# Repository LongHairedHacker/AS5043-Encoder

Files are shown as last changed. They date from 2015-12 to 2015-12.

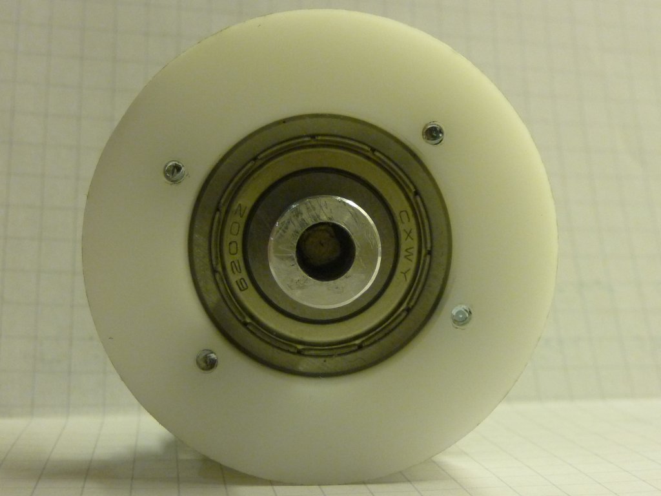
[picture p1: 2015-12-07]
photos/assembled2.jpg

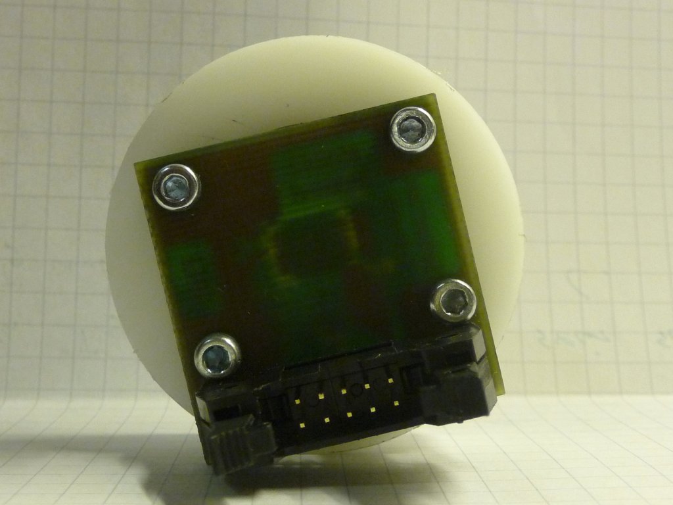
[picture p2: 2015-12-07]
photos/assembled4.jpg

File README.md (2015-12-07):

AS5043-Encoder
==============

This repos contains all the plans and software necessary to build a magnetic rotary encoder using the AS4053.

The setup for this chip is rather simple,
you need a few external components and a neodymium magnet that is attached to your rotating axis.
Then the sensor is placed below the magnet.
Since it uses the magnetic field neither dirt nor light will be a problem.
The sensor will output the angle of the magnet relative to a programmable starting position via analogue output
or via a [SSI](https://en.wikipedia.org/wiki/Synchronous_Serial_Interface)-Style interface.
(See the datasheet for details.)
With 10bit resolution it should be theoretically possible to measure the current angle in 0.35° steps.

The guys at austria microsystems were kind enough to send me 3 AS5043 and 3 AS5030 (similar part 8bit resolution).
*Big thanks to them.*

Mechanical Parts
----------------
There are 2 plans available :

* A version that can be build using a lathe
* A 3D printable version created with open scad
* A 3D printable version created with freecad

The plans for the first version can be found in the repo directory [chasis/lathe](chasis/lathe).
You can simply print out the pdfs and hand them over to someone who has access to a lathe.
He or she should know what to do with them.

For the 3D printable versions simply run the stl files through your 3D printing toolchain.
The 3D printable versions can be found in [chasis/3d_printable_scad](chasis/3d_printable_scad)
and [chasis/3d_printable_freecad](chasis/3d_printable_freecad).

You will also need some M3 screws and nuts which you should find in your favorite hardware store.
For the magnets I'd recommend browsing ebay for 5mmx5mmx5mm neodym magnet cubes.
The ball bearing you'll need is a common 6200Z bearing.
Again try your hardware store or ebay.
There you'll possible also find some M3 5mm long distance bolts, that are used in the lathe version of the chassis.

Software
--------
The software part required some tricks to get it working.
Comparing the signal diagrams for SPI in Atmels datasheet and for *SSI* in the AS5043 a small problem becomes obvious.
The AS5043 needs a clock signal that is high in idle stage and the bits will be shifted out on the positive clock edge.
That sounds very much like the SPI mode 3 in Atmel-speech: Clock high on idle and data will be read on every rising edge.
Leaving us with one problem: The Atmel hardware SPI can read the miso pin only at a clock edge.
As mentioned before data is sampled at the rising edge for mode 3.
So shifting out and reading would be done almost synchronous and due to signal rise and fall times this will probably fail 90% of the time.

The solution is to use mode 2: Clock high on idle and bits are read at the falling edge.
Now we have a different problem.
The first bit will be read before it was shifted out by the AS5043.
Using AVR SPI it is possible to read one byte at time, so two read cycles are required to read the full 16bit encoder output.

The first byte read in mode 2 will look like this:

| Bit 7 | Bit 6 | Bit 5 | Bit 4  | Bit 3 | Bit 2 | Bit 1 | Bit 0 |
|---|---|---|---|---|---|---|---|
| **garbage** | D9 | D8 | D7 | D6 | D5 | D4 | D3 |

Reading the next 8bit will work fine since the 8th bit was shifted out on the last rising edge after reading the first 7 bit.
It will be read as the bit in on the falling edge for the next byte,
which looks like this:

| Bit 7 | Bit 6 | Bit 5 | Bit 4  | Bit 3 | Bit 2 | Bit 1 | Bit 0 |
|---|---|---|---|---|---|---|---|
| D2 | D1 | D0 | OCF | COF | LIN | MAG INC | MAG DEC |

Everything after the *D0*-bit is status information needed in order to decide whether the measurement was valid.
Unfortunately important status bit is still missing.
The 16th bit contains the parity information required to check against transmission errors.
It is shifted out on the last rising edge when reading the second byte. Since the clock line is high afterwards,
the data line will stay on the 16th bits level until the next read is performed.
It can read by manually checking the *MISO* pins state.
The rest is just nifty bit shifting.

It is also important not to use the SS of the AVR mcu for chip select,
since this pin will change to high after reading the first byte, which causes the AS5043 to reset its *SSI* interface.

The code for this can be found in [AS5043.c](firmware/lib/AS5043.c) and in [AS5043.h](firmware/lib/include/AS5043.h).

A simple code for testing can be found in the directory [firmware/demo](firmware/demo).
main.c contains code for an Atmega8 or Atmega328 that reads the encoder, calculates the rotation in degrees and sends out using the uart.
cube.py is a simple receiving is the receiving part running on your computer.
It uses PyOpenGL to display a wireframe cube and rotate it according to the encoders rotation value.

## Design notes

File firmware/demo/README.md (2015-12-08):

Running the Demo
================

Compiling
---------
To compile this example you will need make, avrgcc avr-binutils and the avrlibc.
If you are reading this I assume you already have an avr toolchain in place.
Also you'll need avrdude to flash your avr.

The makefile takes 3 optional parameters:
 * **F_CPU** Clock speed of your controller in Hertz (default: 16000000)
 * **AVRMCU** The name of your microcontroller, currently only atmega8 and atmega32p are supported (default: atemga8)
 * **ISPPORT** The serial interface for `make flash` (default: /dev/ttyACM0)

 To compile and flash the code run (assuming there is a serial bootloader like optiboot present on your controller):
 ```
 make
 make flash
 ```

 If you want to run the code on your Arduino try:
 ```
 make AVRMCU=atmega328p ISPPORT=/dev/ttyACM0
 make AVRMCU=atmega328p ISPPORT=/dev/ttyACM0 flash
 ```

Afterwards connect the encoder and start a terminal emulator of your choice on your serial interface.
Configure it for **38400** Baud, **8** Bit, **N**o Parity and **1** stop bit.
If you start sending newlines to the microcontroller, you should see it respond with measurements in plain ASCII.
If your are seeing binary garbage, you either have the wrong baudrate or degree_mode not set to 1.

You can also run cube_demo.py on this interface if you have PyOpengl and PySerial installed.
It might be necessary to change the SERIAL constant on line 16 to the correct interface.

Connecting the encoder
----------------------

Simply connect the encoder according to the following table:

| AS5043 | Breakout Pin | AVR | Arduino |
|---|---|---|---|
| PROG | 1 | GND | GND |
| DO | 3 | PB4 (MISO) | digital pin 12 |
| CLK | 5 | PB5 (SCK)  | digital pin 13 |
| CS | 7 | PB2 (SS) | digital pin 10 |
| MODE | 9 | GND | GND |
| VDD5V  | 2 | +5v | +5v |
| VSS | 4 | GND | GND |

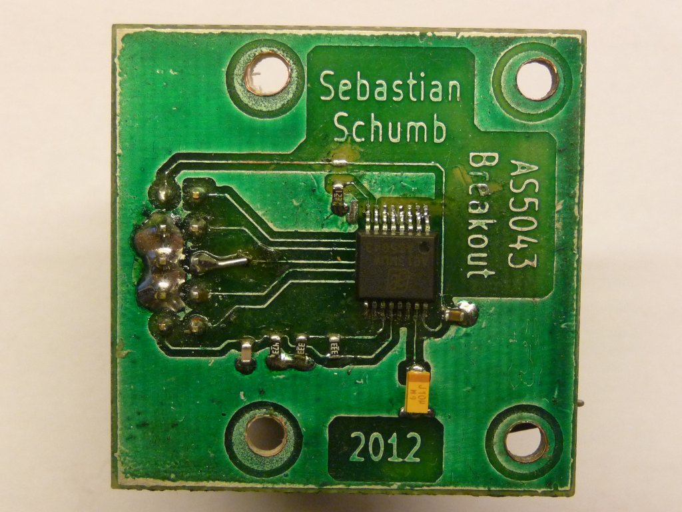
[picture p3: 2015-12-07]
photos/sensorboard_final1.jpg

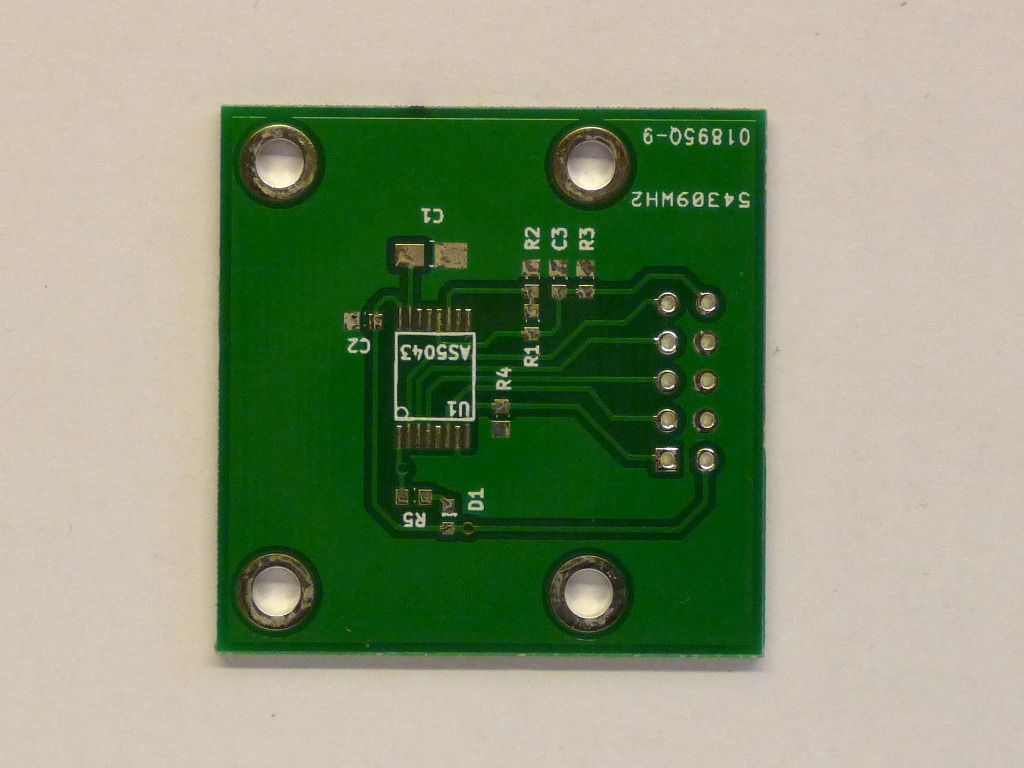
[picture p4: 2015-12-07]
photos/boardv12_bottom.jpg

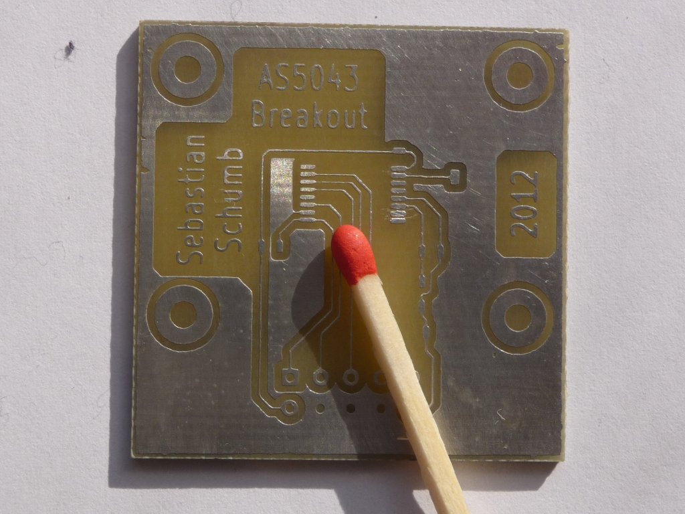
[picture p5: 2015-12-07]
photos/sensorboard_tin2.jpg

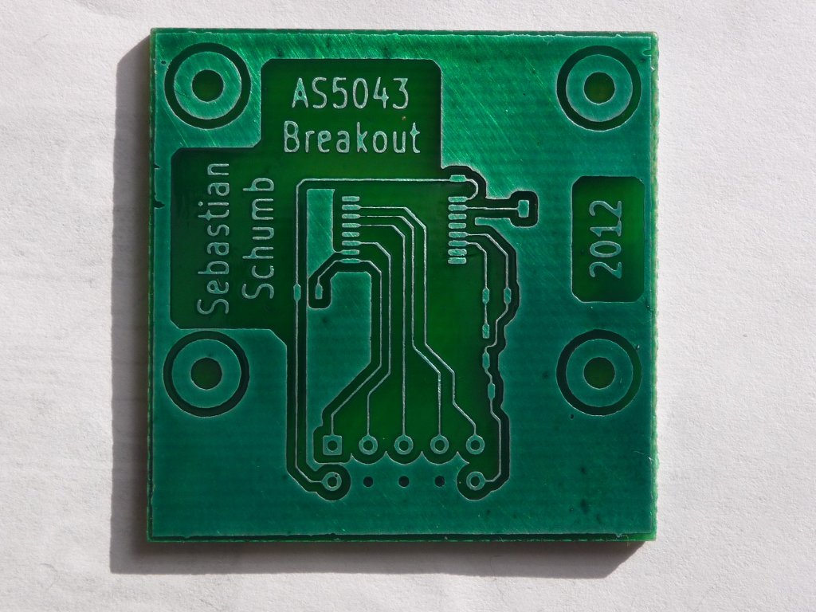
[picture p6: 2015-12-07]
photos/sensorboard_greencoat1.jpg

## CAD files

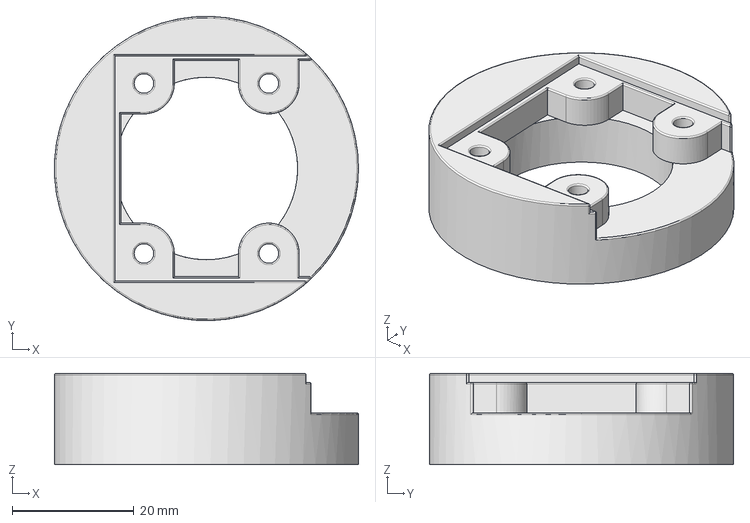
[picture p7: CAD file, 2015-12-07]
chasis/3d_printable_freecad/chasis.fcstd
50.0 x 50.0 x 15.0 mm

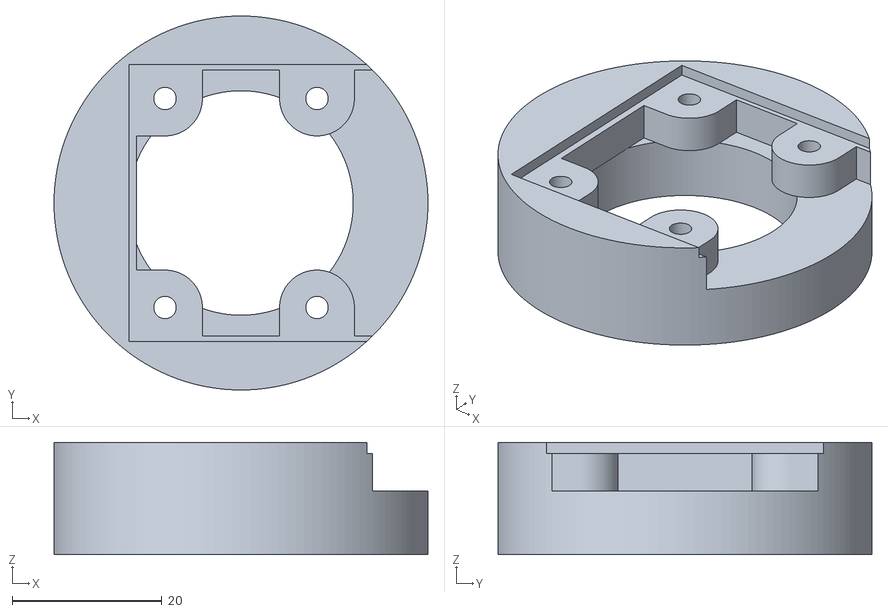
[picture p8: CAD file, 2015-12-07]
chasis/3d_printable_scad/sensor_chasis1.stl
50.0 x 50.0 x 15.0

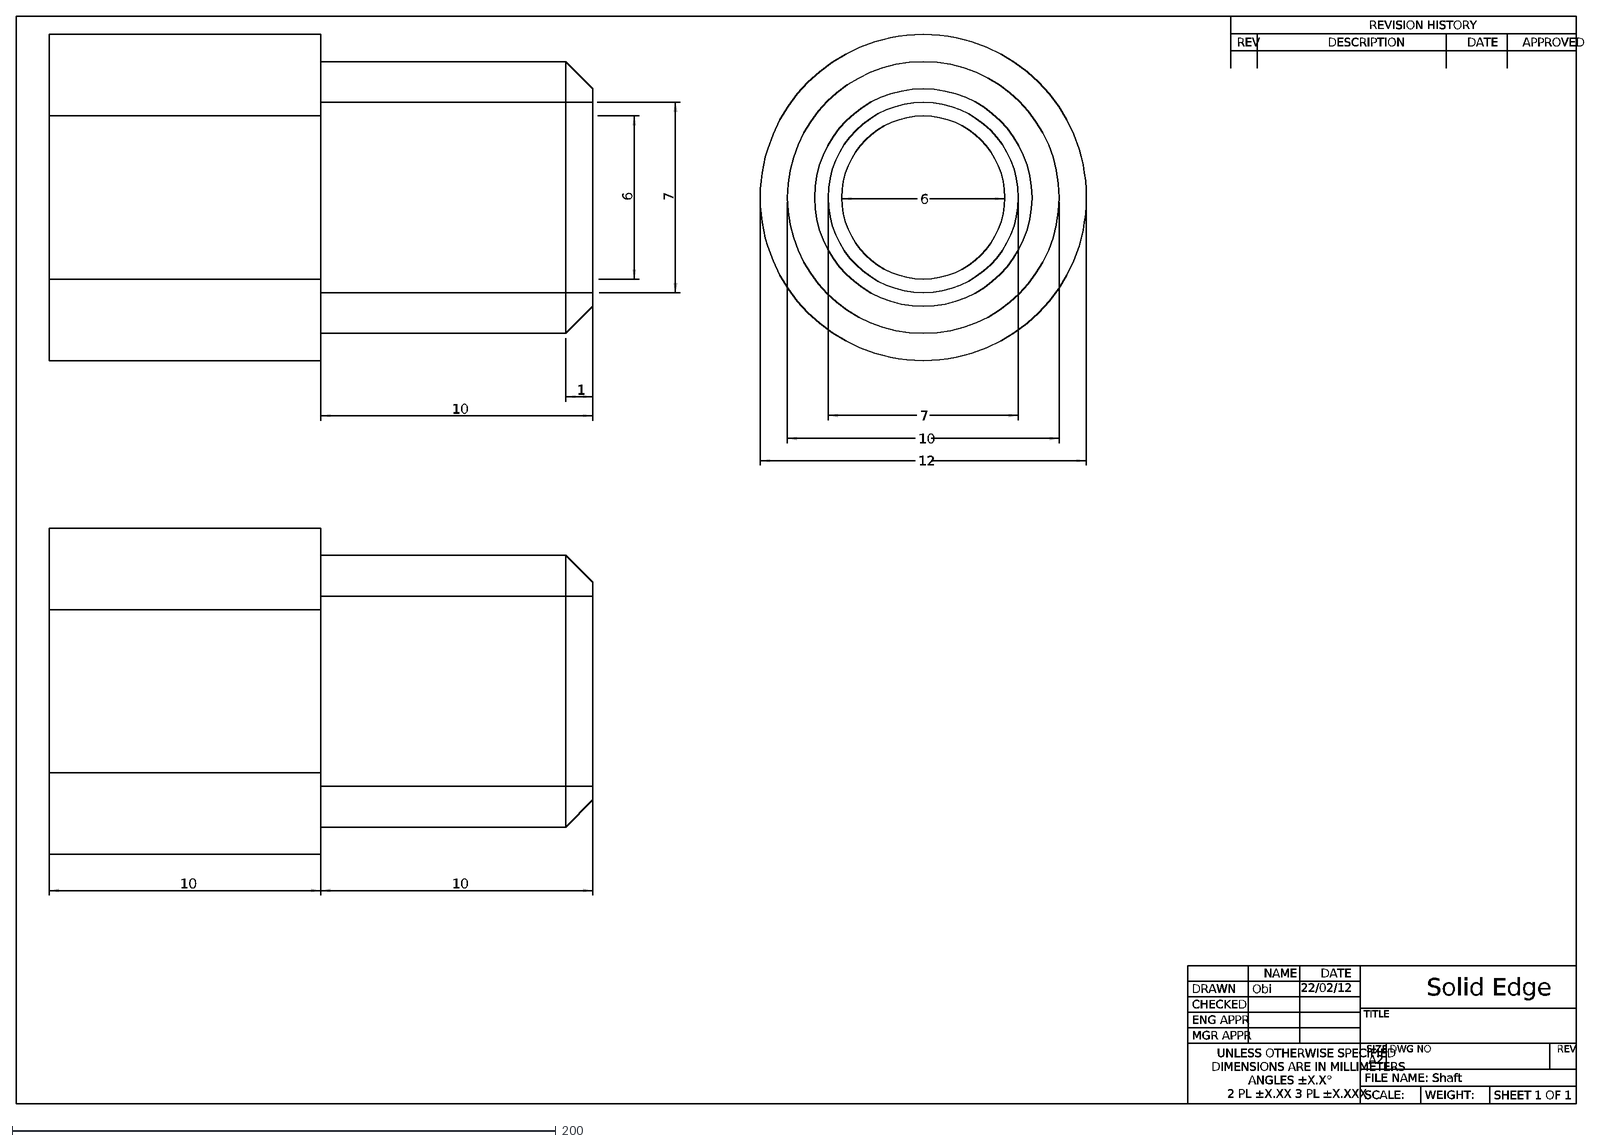
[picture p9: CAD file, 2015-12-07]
chasis/lathe/shaft.dxf
DRAWN
CHECKED
ENG APPR
MGR APPR
UNLESS OTHERWISE SPECIFIED
DIMENSIONS ARE IN MILLIMETERS
ANGLES ±X.X°
2 PL ±X.XX 3 PL ±X.XXX
NAME
DATE
Solid Edge
TITLE
SIZE
A2
DWG NO
REV
SCALE:
WEIGHT:
REVISION HISTORY
DESCRIPTION
APPROVED
1
10
6
7
12
Obi
22/02/12
FILE NAME: Shaft
SHEET 1 OF 1

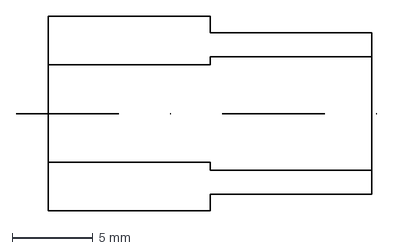
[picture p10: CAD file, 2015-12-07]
chasis/prototype/shaft.dxf
22.3 x 12.0 mm

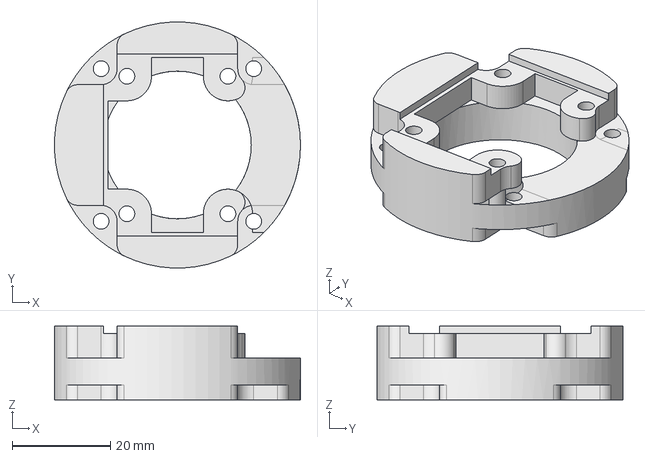
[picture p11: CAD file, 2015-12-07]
chasis/testrig_freecad/testrig.fcstd
50.0 x 49.9 x 15.0 mm

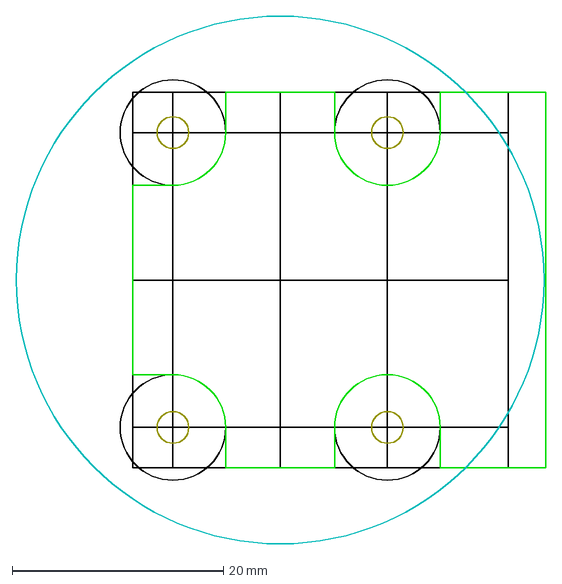
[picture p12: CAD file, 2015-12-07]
chasis/3d_printable_scad/cut-out.dxf
50.2 x 50.0 mm

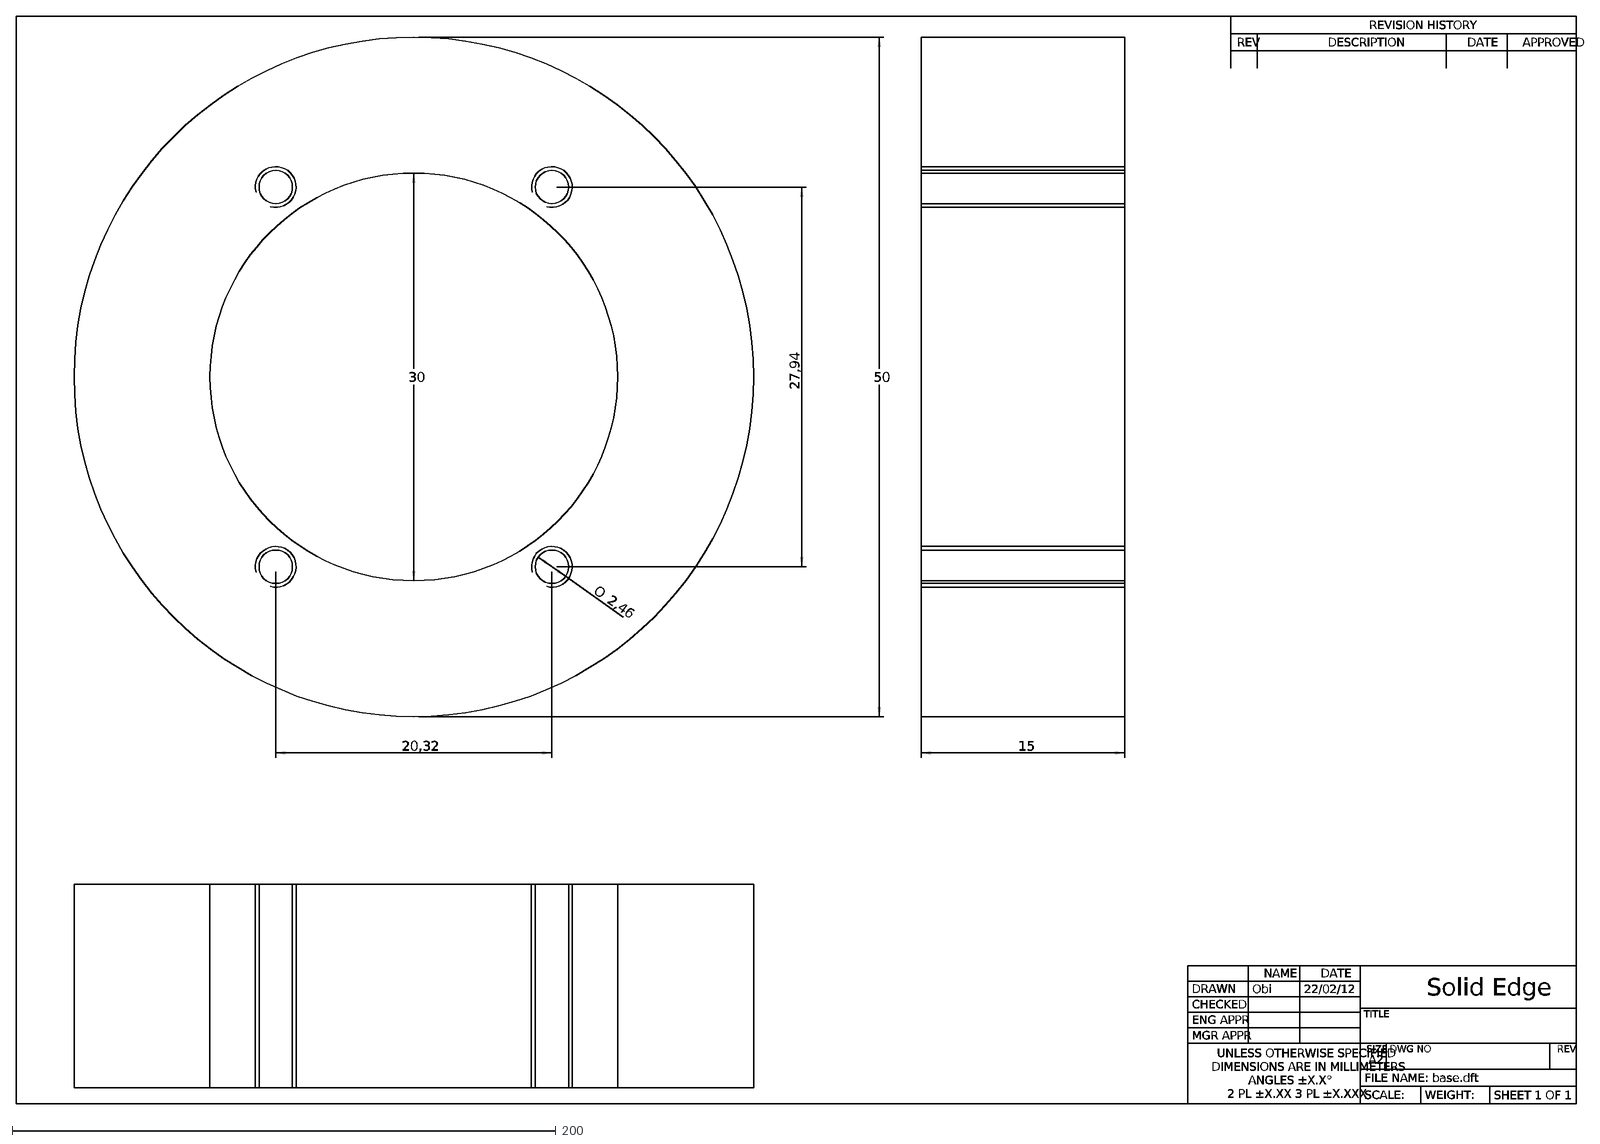
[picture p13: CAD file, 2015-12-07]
chasis/lathe/base.dxf
DRAWN
CHECKED
ENG APPR
MGR APPR
UNLESS OTHERWISE SPECIFIED
DIMENSIONS ARE IN MILLIMETERS
ANGLES ±X.X°
2 PL ±X.XX 3 PL ±X.XXX
NAME
DATE
Solid Edge
TITLE
SIZE
A2
DWG NO
REV
SCALE:
WEIGHT:
REVISION HISTORY
DESCRIPTION
APPROVED
20,32
27,94
O
2,46
30
50
15
Obi
22/02/12
FILE NAME: base.dft
SHEET 1 OF 1

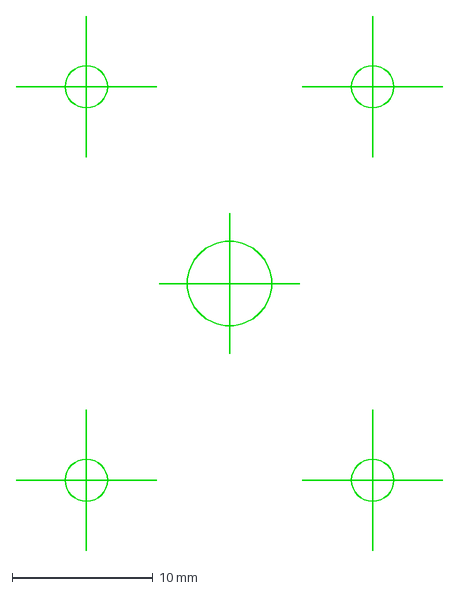
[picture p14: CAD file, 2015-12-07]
chasis/prototype/base.dxf
30.3 x 37.9 mm

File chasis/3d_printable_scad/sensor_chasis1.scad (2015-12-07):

$fn = 128;


difference() {
			// 6.5mm above Zero pane, 8.5 below 
			// 5.0mm between board and bearing
			// 1.5mm to fit the board into
			translate([0,0,-1]) cylinder(r=25, h=15, center=true);
	union() {
		translate([0,0,3]) linear_extrude(file="cut-out.dxf", 
                                            layer="umriss", 
                                            height=6,
                                            center=true);

		translate([5,0,5+2]) cube(size=[40,37,4], center=true);
		
		translate([0,0,-1]) linear_extrude(file="cut-out.dxf",
                                            layer="holes",
                                            height=16,
                                            center=true);

		translate([0,0,-4.5]) cylinder(r=15, h=9, center=true);

		

	}
}	

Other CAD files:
chasis/3d_printable_freecad/freecad.stl
chasis/testrig_freecad/testrig.stl

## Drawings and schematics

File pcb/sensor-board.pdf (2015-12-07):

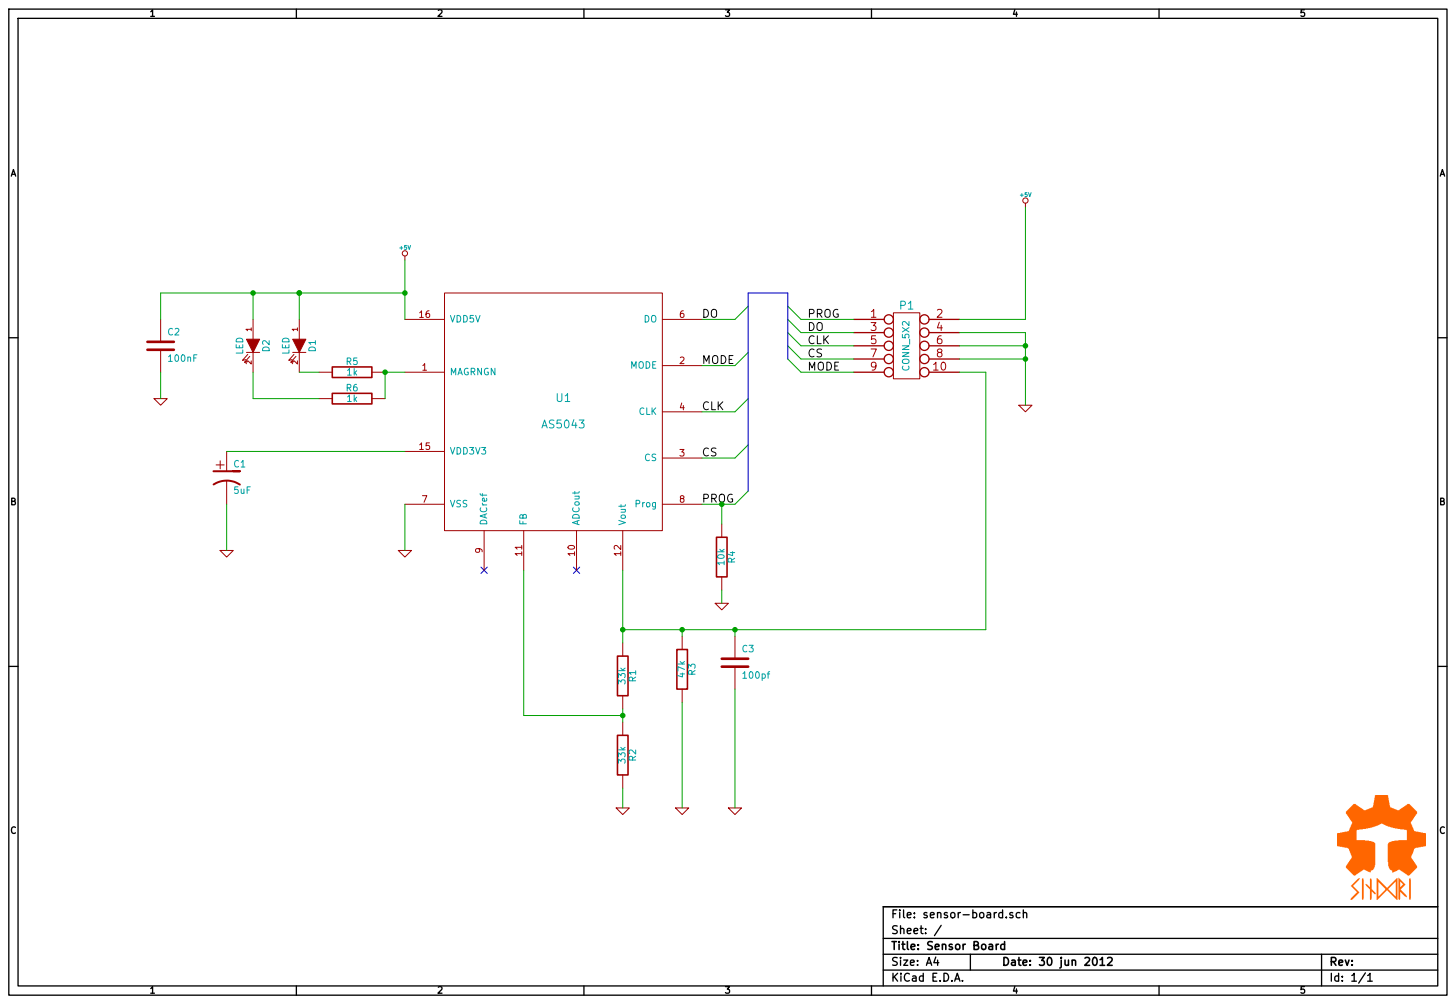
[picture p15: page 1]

File: sensor-board.sch Sheet: / 10k R4

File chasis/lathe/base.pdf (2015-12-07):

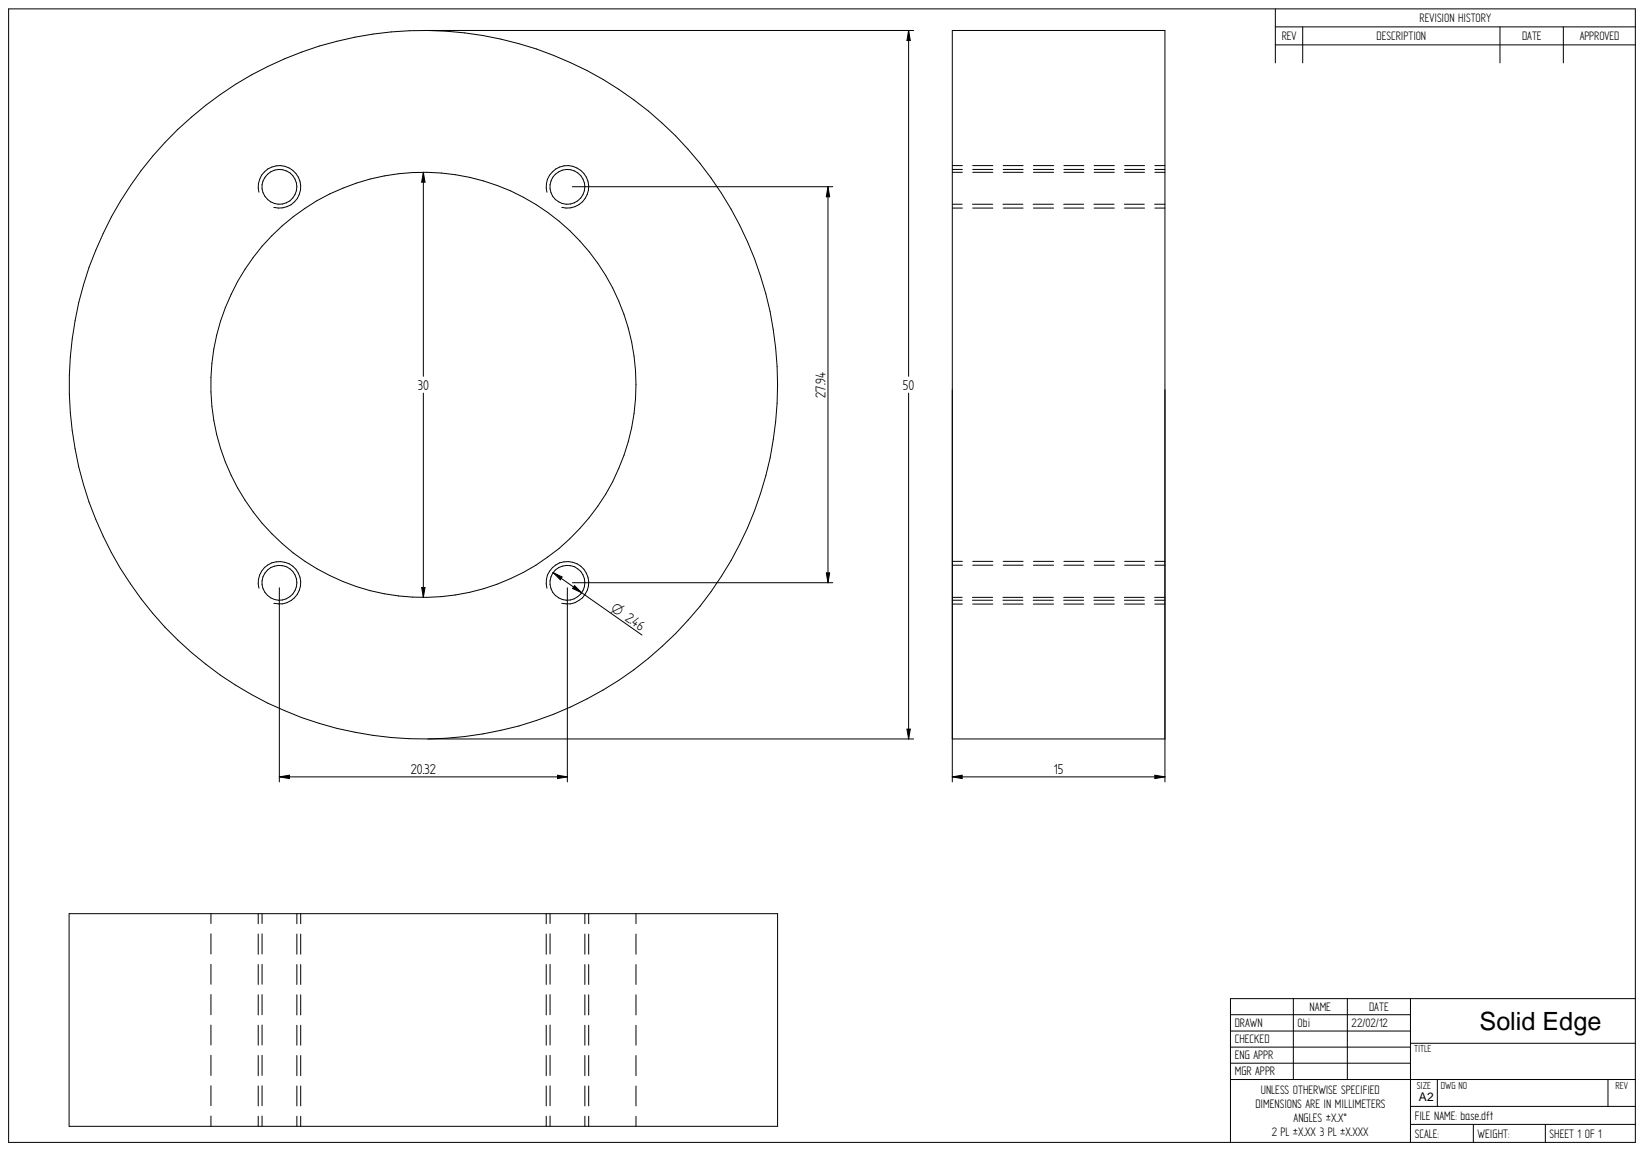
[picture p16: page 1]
SCALE:; WEIGHT:; SHEET 1 OF 1

REVISION HISTORY

REV | DESCRIPTION | DATE | APPROVED

NAME | DATE | Solid Edge

DRAWN | Obi | 22/02/12
CHECKED
ENG APPR | | | TITLE

MGR APPR
UNLESS OTHERWISE SPECIFIED DIMENSIONS ARE IN MILLIMETERS ANGLES ±X.X° 2 PL ±X.XX 3 PL ±X.XXX | SIZE A2 | DWG NO | REV

FILE NAME: base.dft

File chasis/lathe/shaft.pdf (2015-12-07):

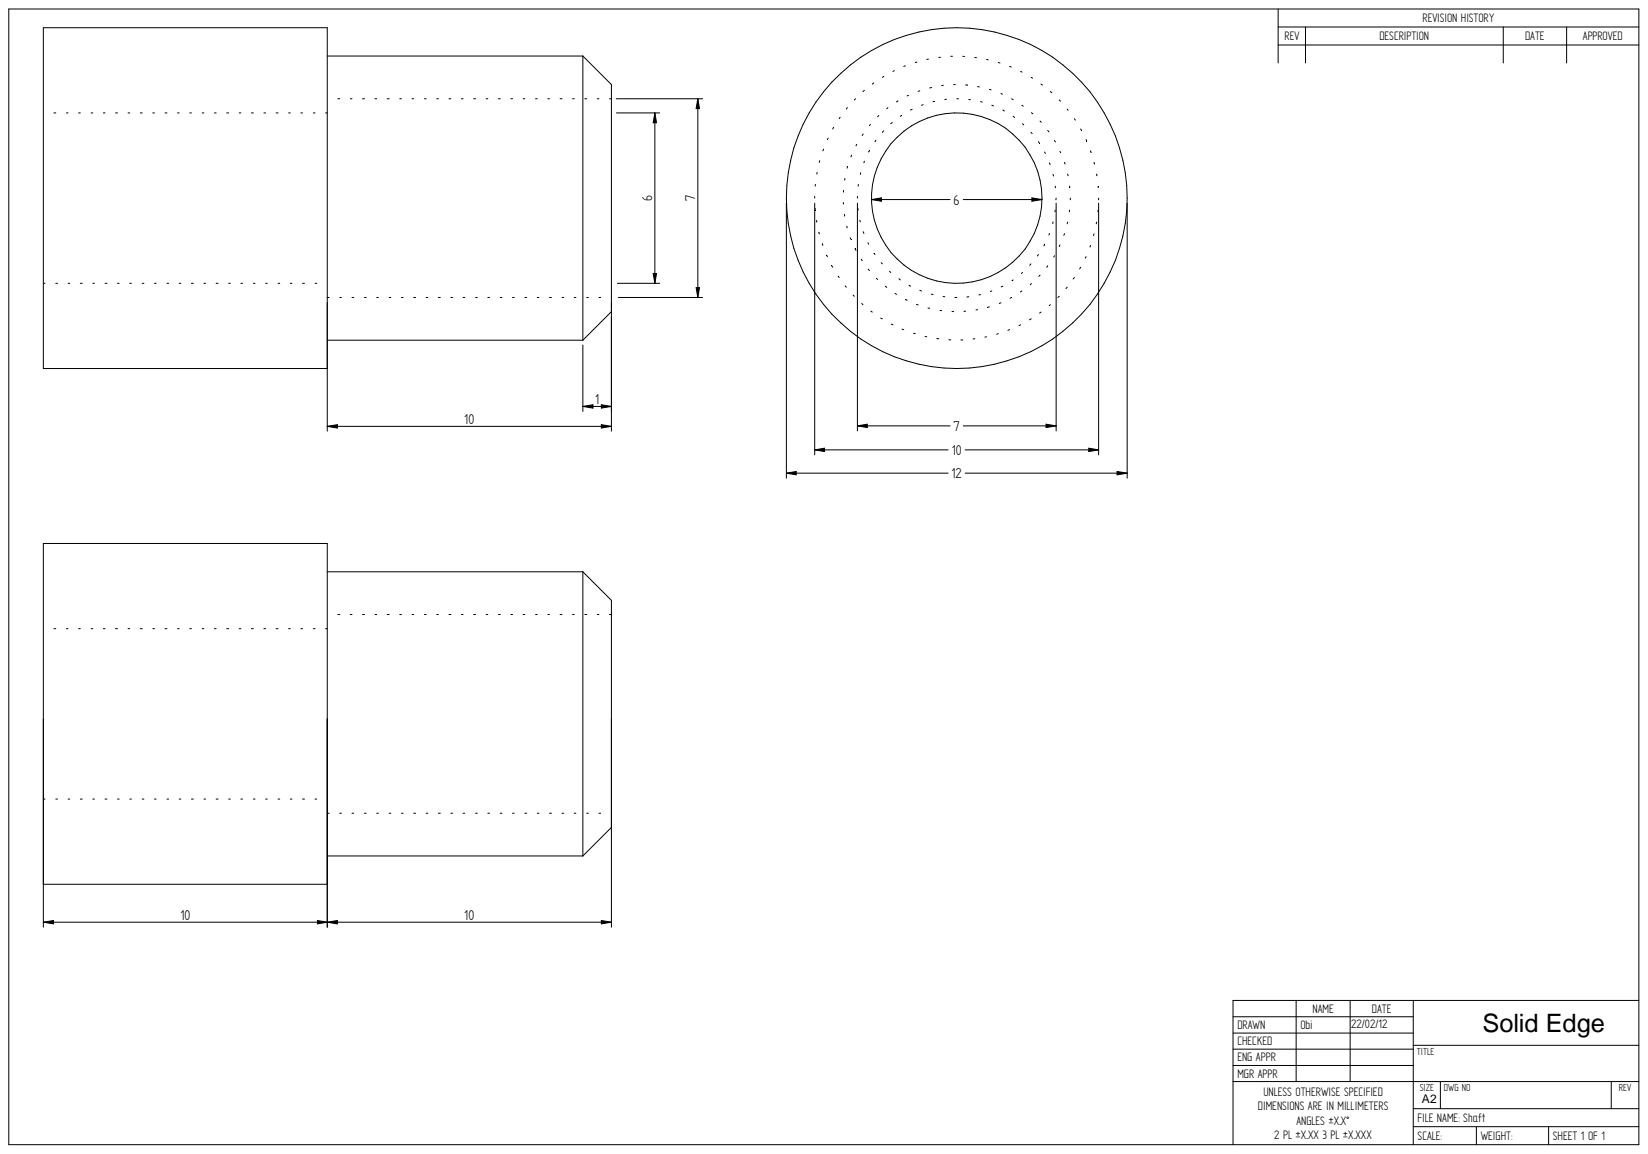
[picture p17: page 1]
SCALE:; WEIGHT:; SHEET 1 OF 1

REVISION HISTORY

REV | DESCRIPTION | DATE | APPROVED

DRAWN | Obi | 22/02/12
CHECKED
ENG APPR | | | TITLE

NAME | DATE | Solid Edge

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

FILE NAME: Shaft

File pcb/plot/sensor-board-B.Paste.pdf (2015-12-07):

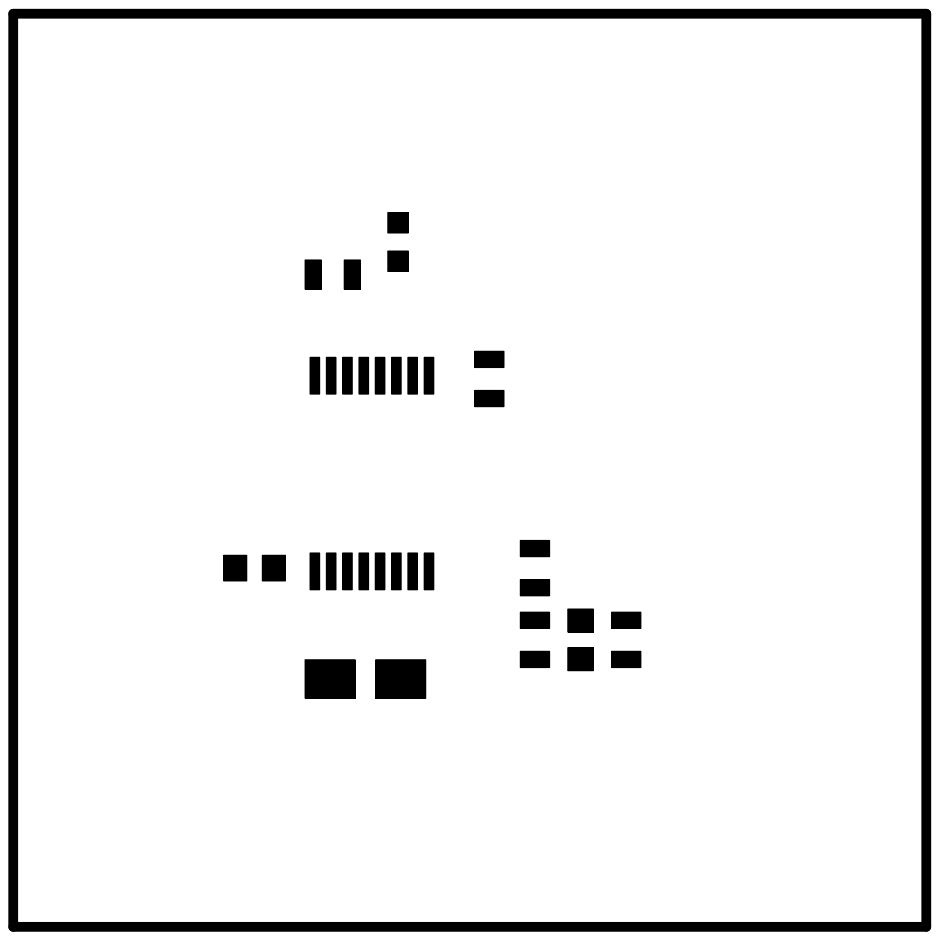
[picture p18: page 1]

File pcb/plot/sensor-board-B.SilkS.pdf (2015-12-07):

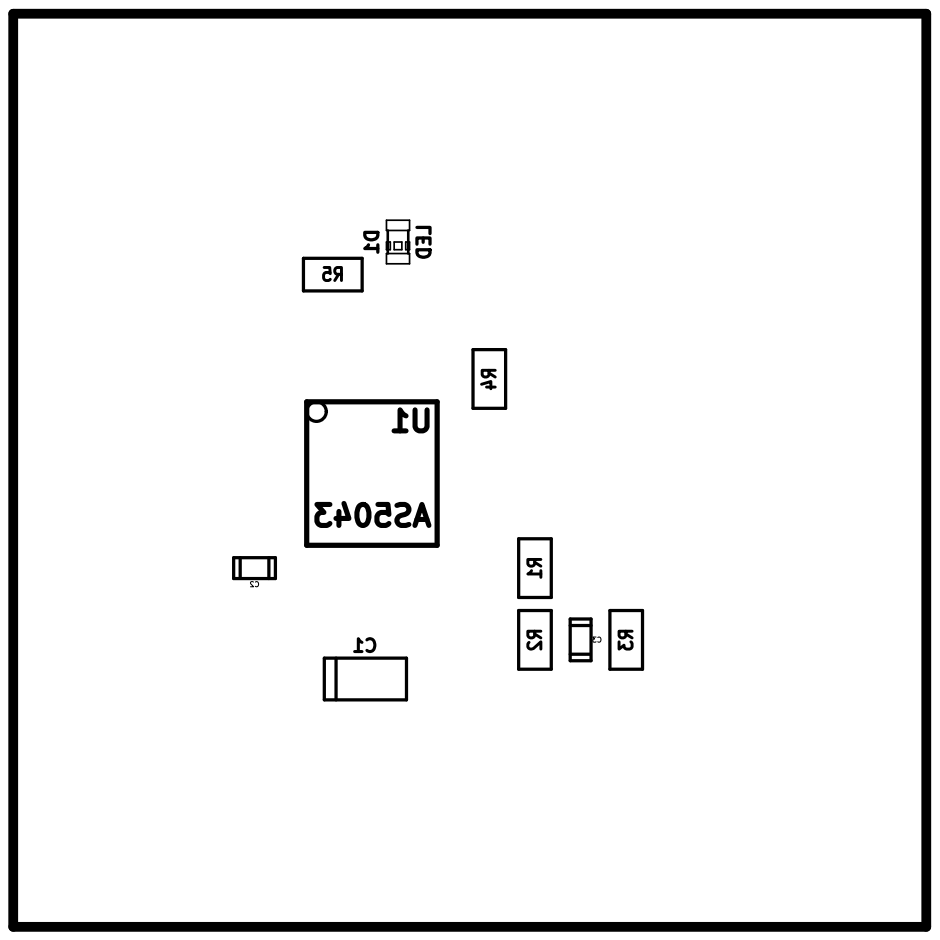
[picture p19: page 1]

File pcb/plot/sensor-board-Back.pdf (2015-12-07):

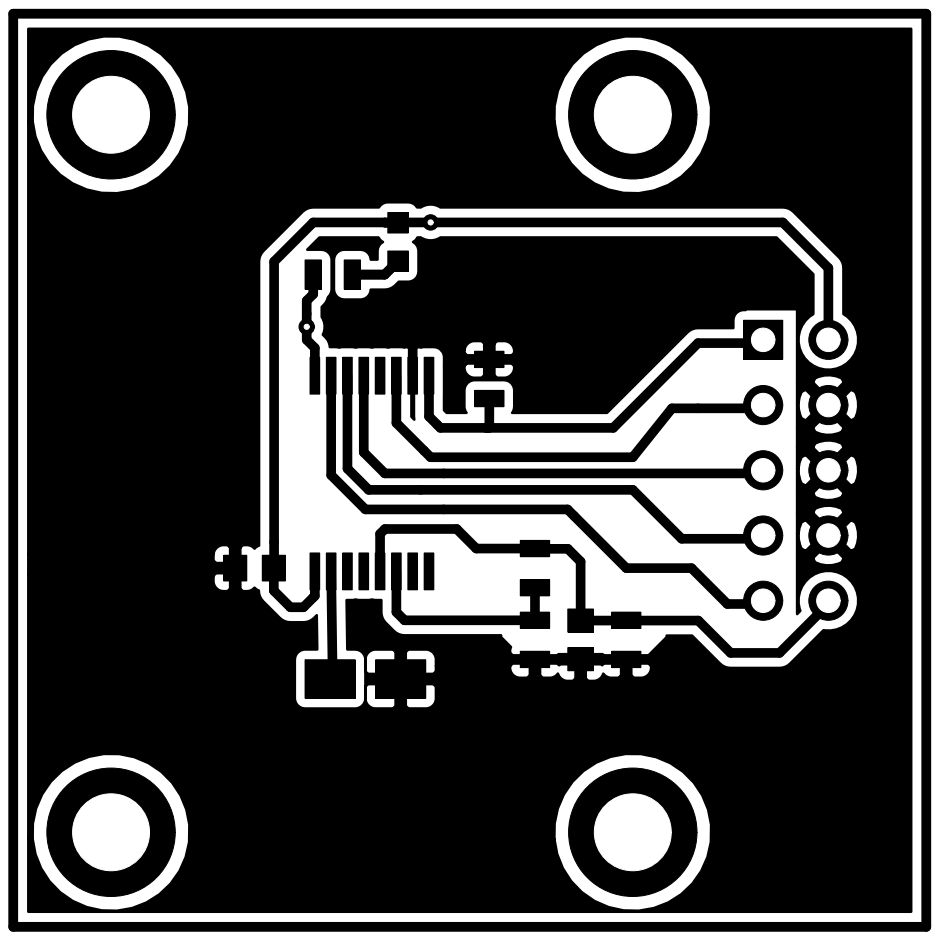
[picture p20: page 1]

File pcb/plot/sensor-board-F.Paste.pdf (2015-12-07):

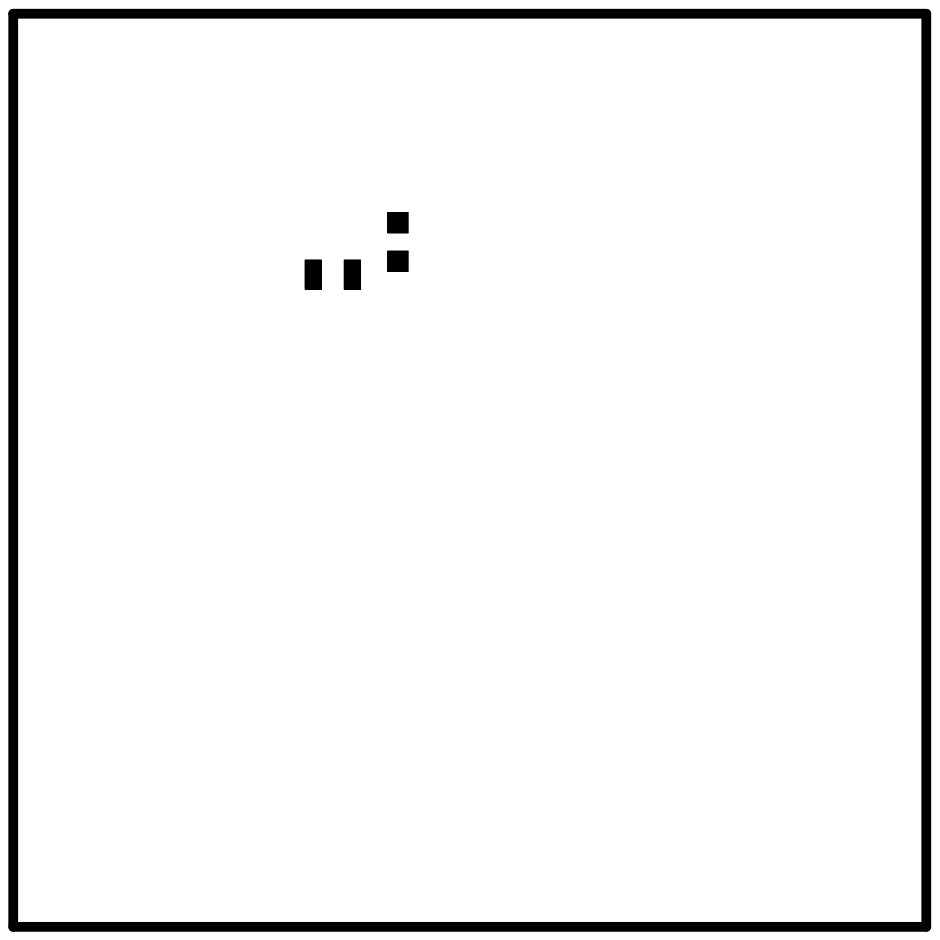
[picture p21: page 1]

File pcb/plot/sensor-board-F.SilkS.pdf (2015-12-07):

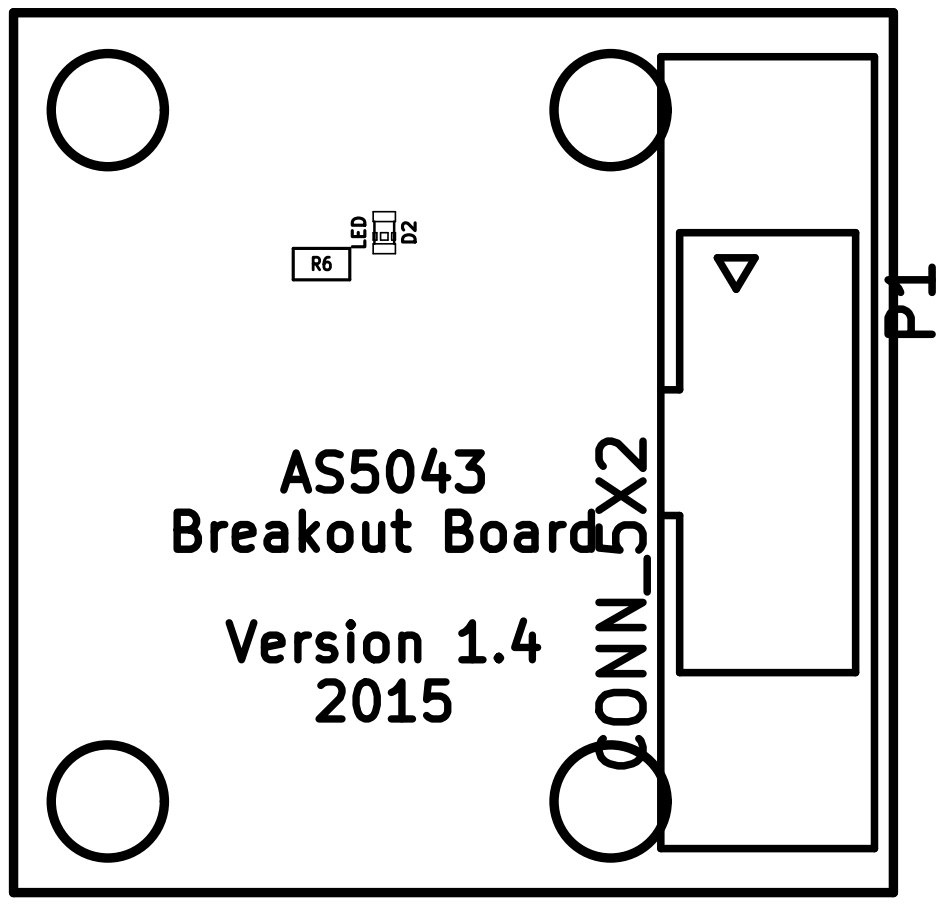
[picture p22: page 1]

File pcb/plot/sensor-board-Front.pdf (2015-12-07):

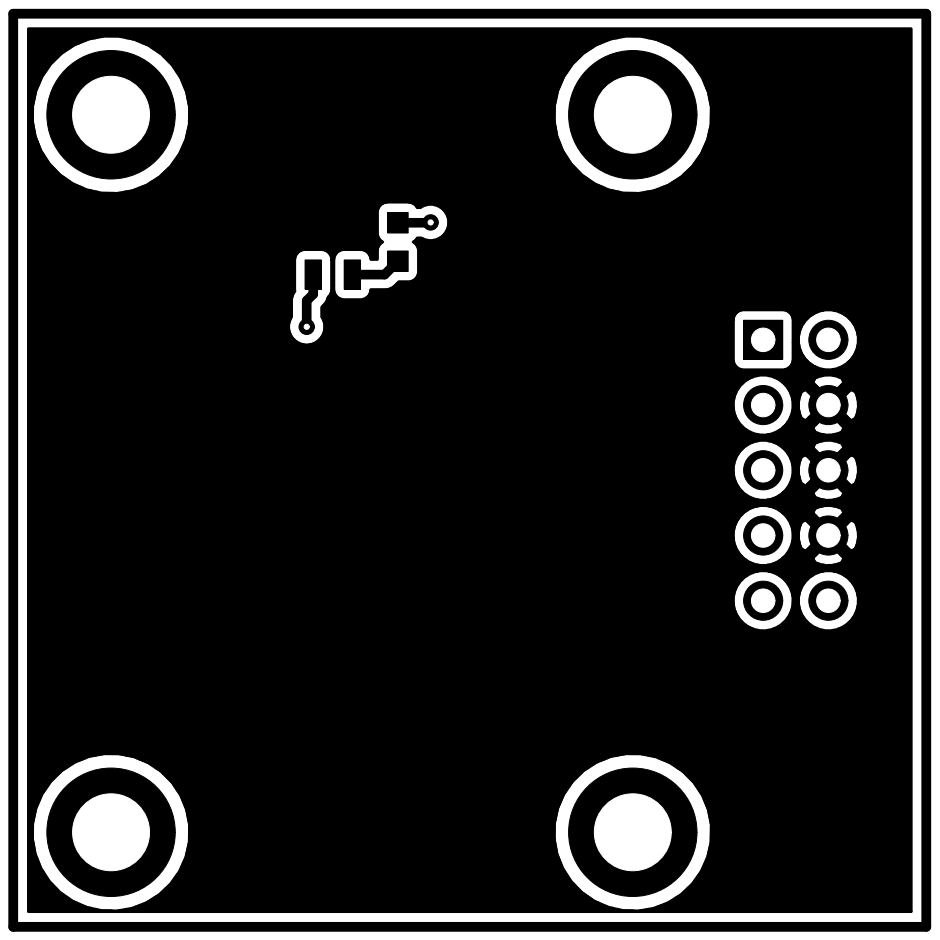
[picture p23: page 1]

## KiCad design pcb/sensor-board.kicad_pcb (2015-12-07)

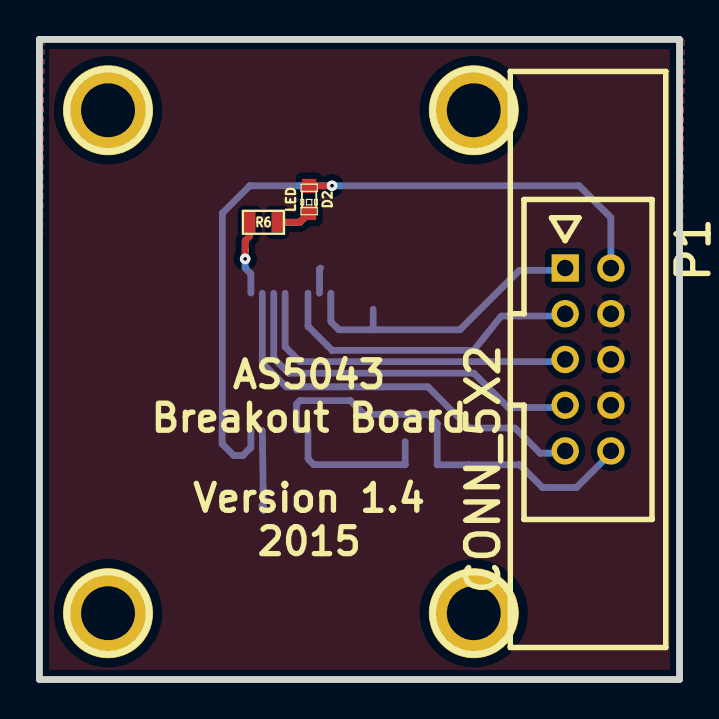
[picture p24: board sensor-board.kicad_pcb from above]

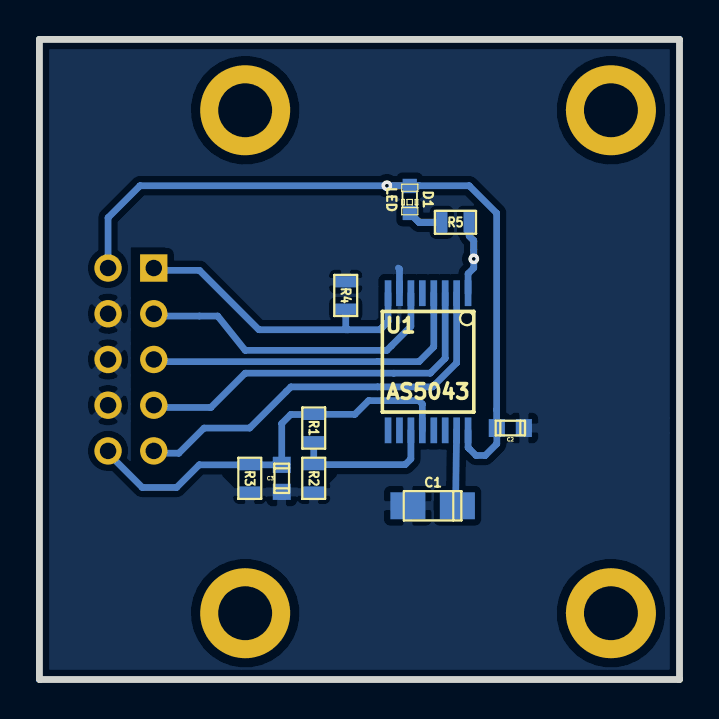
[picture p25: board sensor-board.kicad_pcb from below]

Board: 2 copper layers, 35.6 x 35.6 mm, 13 parts (10 on the bottom side), 13 nets.

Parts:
C1: 5uF; c_tant_A
C2: 100nF; c_0603
C3: 100pf; c_0603
D1, D2: LED; LED-0603
P1: CONN_5X2; he10-lock
R1, R2: 33k; SM0603
R3: 47k; SM0603
R4: 10k; SM0603
R5, R6: 1k; SM0603
U1: AS5043; SSOP16_WIDE

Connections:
+5V: C2.1, D1.1, D2.1, P1.2, U1.16
/CLK: P1.5, U1.4
/CS: P1.7, U1.3
/DO: P1.3, U1.6
/MODE: P1.9, U1.2
/PROG: P1.1, R4.1, U1.8
GND: C1.2, C2.2, C3.2, P1.4, P1.6, P1.8, R2.2, R3.2, R4.2, U1.7
unnamed: C1.1, U1.15
unnamed: C3.1, P1.10, R1.1, R3.1, U1.12
unnamed: D1.2, R5.1
unnamed: D2.2, R6.1
unnamed: R1.2, R2.1, U1.11
unnamed: R5.2, R6.2, U1.1

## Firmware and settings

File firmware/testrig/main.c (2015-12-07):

#include <avr/io.h>
#include <util/delay.h>
#include <stdlib.h>

#include "AS5043.h"
#include "uart.h"

const uint8_t degree_mode = 0;

int main(void) {

	uint16_t data;
	uint16_t rot;
	//uint8_t chr;
	char str[5];
	uart_init();

	AS5043_setup();

	DDRC = 0xFF;
	DDRD |= (1 << PD4);

	while(1) {

		data = AS5043_readout();

		if(AS5043_checkParity(data) && (uart_getc() != -1)) {

			rot = AS5043_getPos(data);

			if(degree_mode) {
				rot = (rot * 45) / 128;
			}

			itoa(rot, str, 10);
			uart_puts(str);
			uart_puts("\r\n");

			PORTD |= (1 << PD4);
			_delay_us(1);
			PORTD &= ~(1 << PD4);
		}
		_delay_ms(10);
	}


}

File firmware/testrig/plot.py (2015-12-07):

#! /usr/bin/env python


import serial
from time import sleep
from datetime import datetime

import matplotlib.pyplot as plt



MAX_GRAD = 900

def read_angle():
	line = ""
	while len(line) == 0:
		ser.write("a")
		line = ser.readline()
	return int(line[:-2])



ser = serial.Serial('/dev/ttyUSB0', 9600, timeout=0.032)
if not ser:
	print "Unable to open serial port"
	sys.exit(1)

values = []
samples = []
sample = 0

starttime = datetime.now()
for x in range(0,1000):
	ang = read_angle();
	values.append(ang)
	samples.append(sample)
	sample += 1

print "Done"
plt.plot(samples,values,'+',samples,values)
plt.show()


grads = []
for x in range(1,1000):
	cur_grad = values[x] - values[x-1];
	if(abs(cur_grad) < MAX_GRAD):
		grads.append(cur_grad)


plt.hist(grads,len(grads))
plt.show()

""""
avg_grad = 0
for grad in grads:
	avg_grad += grad / len(grads)

print "Avarage gradient: %f" % avg_grad

avg_grad_error = 0
for grad in grads:
	avg_grad_error += abs(grad - avg_grad) / len(grads)

print "Avarage gradient error: %f" % avg_grad_error
"""

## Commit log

2015-12-07 Initial commit Collected all usefull things from old repo
    [base.dxf, chasis.fcstd, cut-out.dxf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]
2015-12-07 General sorting and cleanup
    [freecad.stl, sensor_chasis1_bin.stl]
2015-12-08 Added breakout board pins to readme
